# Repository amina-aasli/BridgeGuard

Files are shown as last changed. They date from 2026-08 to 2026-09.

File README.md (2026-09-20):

# BridgeGuard
**Intelligent urban flood risk prevention system using computer vision and edge computing**

BridgeGuard monitors water levels under bridges in real time, predicts flood risk using computer vision models, and automatically triggers alerts before a flood becomes critical.

---

## The problem

In Morocco, as in many other regions, flash floods regularly damage bridges and cut off vital roads often without alerts fast or localized enough. BridgeGuard addresses a simple question: **how can a bridge be monitored continuously, without human intervention, and warn people before it's too late?**

## System architecture

```mermaid
graph LR
    subgraph Field["Field Layer"]
        POWER[Power Supply]
        MODULE4G[4G Module]
        CAM[Camera 5MP]
        MPU[MPU6050]
        HCSR[HC-SR04]
        DEBIT[Flow Sensor]
        PLUIE[Rain Gauge]
    end

    subgraph Processing["Processing Layer"]
        RPI[Raspberry Pi 4]
        SUPA[(Supabase)]
        N8N[n8n]
    end

    subgraph Alert["Alert Layer"]
        APP[Web Application]
        SMS[SMS + Alerts]
        V2I[V2I Notification<br/>Automatic Rerouting]
        MAPS[Maps API]
        GEO[GPS Geofencing]
    end

    POWER --> MODULE4G
    CAM --> RPI
    MPU --> RPI
    HCSR --> RPI
    DEBIT --> RPI
    PLUIE --> RPI
    MODULE4G <--> RPI
    RPI --> SUPA
    SUPA --> N8N
    N8N --> APP
    N8N --> SMS
    N8N -.-> V2I
    GEO -.-> V2I
    MAPS --> V2I

    style RPI fill:#1a1a2e,stroke:#4a9eff,color:#fff
    style SUPA fill:#1a1a2e,stroke:#ff6b6b,color:#fff
    style V2I fill:#1a1a2e,stroke:#ffa94d,color:#fff
```

## How it works

1. **Acquisition**  a camera and 4 physical sensors (water level, vibration, flow rate, rainfall) continuously collect data on the bridge.
2. **AI analysis**  a semantic segmentation model (YOLOv8n-seg) identifies and quantifies water surfaces in the image, combined with OpenCV analysis (color-based segmentation + current speed via optical flow).
3. **Decision**  a threshold-based engine aggregates these signals into a risk score (low / moderate / critical).
4. **Active safety**  if the risk becomes critical, a second model (YOLOv8n) verifies the bridge is clear of vehicles before automatically triggering a physical barrier closure.
5. **Alert**  authorized engineers receive an SMS/email in under 4 seconds; a public dashboard informs residents of the bridge's status in real time.

## Results

| Metric | Result |
|---|---|
| Vehicle detection (YOLOv8n) | mAP50 = 0.926 |
| Water level precision (HC-SR04) | ± 0.3 cm |
| Alert response time | < 4 seconds |
| Segmentation inference speed | 12.5 ms/image |

## Tech stack

- **Edge**: Raspberry Pi 4, Python
- **Computer vision**: YOLOv8n-seg, YOLOv8n, OpenCV
- **Cloud**: Supabase (PostgreSQL + Realtime), n8n
- **Web**: React + TypeScript, Node.js + Express
- **Mechanical design**: CATIA (IP67 polycarbonate enclosure)
- **Power**: solar panel + MPPT + LiPo battery
```mermaid
graph LR
    PANEL[Solar Panel<br/>12V / 20W]
    MPPT[MPPT Controller]
    BATTERY[LiPo Battery<br/>12V / 10Ah]
    BUCK[DC-DC Buck<br/>Regulator]

    PANEL --> MPPT
    MPPT --> BATTERY
    BATTERY --> BUCK

    style PANEL fill:#1a1a2e,stroke:#ffa94d,color:#fff
    style BATTERY fill:#1a1a2e,stroke:#4a9eff,color:#fff
```

The MPPT controller optimizes solar charging efficiency (+30% vs a standard PWM controller), while the buck regulator ensures a stable 5V/3A output protecting the Raspberry Pi and sensors from battery voltage fluctuations. Total system consumption averages ~7W, giving roughly 24h of autonomy without sunlight.
## Ongoing extensions

BridgeGuard is expanding into a connected mobility ecosystem:
- **[BridgeGuard-Beacon](./beacon)** — anonymous driver notification via Wi-Fi captive portal, pre-calculated deviation routing, and an Evil Twin threat model with independent physical failsafe, validated end-to-end
- **BridgeGuard-OBU** — opt-in in-vehicle badge for connected fleets (upcoming)

## Repo structure

```
BridgeGuard/
├── hardware/       → CATIA design + electronic schematic
├── software/       → decision engine, OpenCV processing
├── ml-models/      → YOLOv8 training notebooks
├── web-app/        → frontend, backend, database
└── beacon/         → BridgeGuard-Beacon (Phase 2, see beacon/README.md)
```

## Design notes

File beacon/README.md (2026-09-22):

# BridgeGuard-Beacon

**Anonymous flood-alert notification via Wi-Fi captive portal, with an independent physical failsafe**

Second phase of BridgeGuard, extending a bridge flood-monitoring system with a Vehicle-to-Infrastructure (V2I) notification channel that reaches any smartphone, with zero app install and zero prerequisite.

---

## The problem

BridgeGuard (Phase 1) detects flood risk and closes a physical barrier automatically, but the driver approaching the bridge has no way of knowing *why* traffic is stopped, or where to go instead. Most vehicles have no native V2X connectivity, so any notification channel has to work with a standard smartphone, out of the box, without depending on installed apps.

## Why 500 m, why 3 axes

The geofencing radius isn't arbitrary, it comes directly from the physics of the approach:

- Speed limit at the bridge: **60 km/h → 16.67 m/s**
- Required advance warning window: **30 s** (reaction + comprehension + maneuver time)
- → **d = 16.67 × 30 ≈ 500 m**

Three vehicle access axes converge on the bridge (North, South-West via Bd Oued Issil, South-East via Palmeraie — two entry roads). Each was mapped and validated in QGIS to confirm beacon placement sits within the 500 m radius while accounting for real road topology.

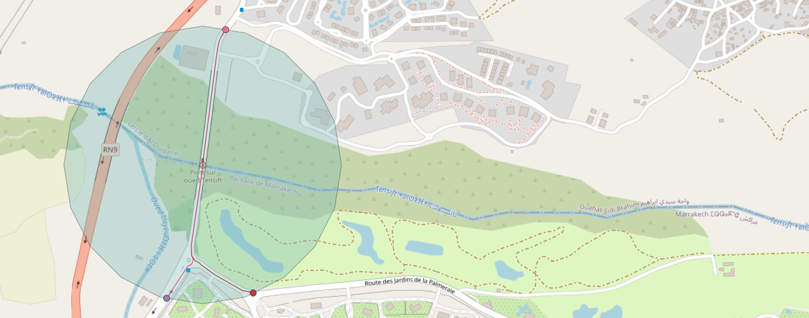
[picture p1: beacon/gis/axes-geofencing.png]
QGIS site analysis


## Architecture

```mermaid
graph TD
    subgraph Driver["Driver's smartphone"]
        PHONE[Connects to open Wi-Fi]
    end

    subgraph Beacon["ESP32 Beacon — SoftAP + STA combined"]
        AP[SoftAP<br/>open network, no password]
        DNS[DNS Server<br/>wildcard spoofing]
        HTTP[Async HTTP Server<br/>captive portal routes]
        PAGE[Alert page<br/>deviation + Maps deep link]
    end

    subgraph Cloud["Central system"]
        SUPA[(Supabase<br/>system_status)]
        DECISION[DecisionEngine<br/>Raspberry Pi — Phase 1]
    end

    PHONE -->|open network detected| AP
    AP --> DNS
    DNS -->|all queries redirected| HTTP
    HTTP --> PAGE
    PAGE -.->|deep link, driver's own data| MAPS[Google Maps]

    DECISION --> SUPA
    SUPA -->|active_alert, risk_level| HTTP

    style AP fill:#1a1a2e,stroke:#4a9eff,color:#fff
    style PAGE fill:#1a1a2e,stroke:#ff6b6b,color:#fff
    style SUPA fill:#1a1a2e,stroke:#3fb950,color:#fff
```

## How it works

1. **Detection** — the ESP32 broadcasts an open Wi-Fi network (`BridgeGuard-Alerte`) near each bridge access axis. No password, no app; the phone's own OS (iOS Captive Network Assistant, Android Connectivity Check) is the only client needed.
2. **Redirection** — a lightweight DNS server resolves every domain query to the beacon's own IP, and an async HTTP server intercepts OS-specific captive-portal probes (`/generate_204`, `/hotspot-detect.html`) to serve the alert page automatically.
3. **Guidance** — the page opens a deep link straight into the driver's own Maps app, from a hardcoded beacon-position origin to a pre-verified safe point, no live routing computed on-device, no dependency on the driver's GPS fix.
4. **Sync with the central system** — running in combined `WIFI_AP_STA` mode, the same ESP32 polls a read-only Supabase endpoint every 10 s to read the already-computed `active_alert` flag from the central DecisionEngine (Phase 1), no risk logic duplicated on the beacon.
5. **Physical failsafe** — a dedicated GPIO on the central Raspberry Pi drives an upstream warning panel, triggered in the same call as the barrier closure, independent of Wi-Fi, smartphones, or any voluntary technology adoption.

## Pre-calculated deviation routes

The beacon never computes a route on-device — it only knows two fixed points per axis: its own position, and a verified nearby point that is outside the risk zone. Guidance itself is entirely delegated to the driver's own Maps app.

| Axe | Balise (origine) | Point sûr (destination) | Distance | Itinerary |
|---|---|---|---|---|
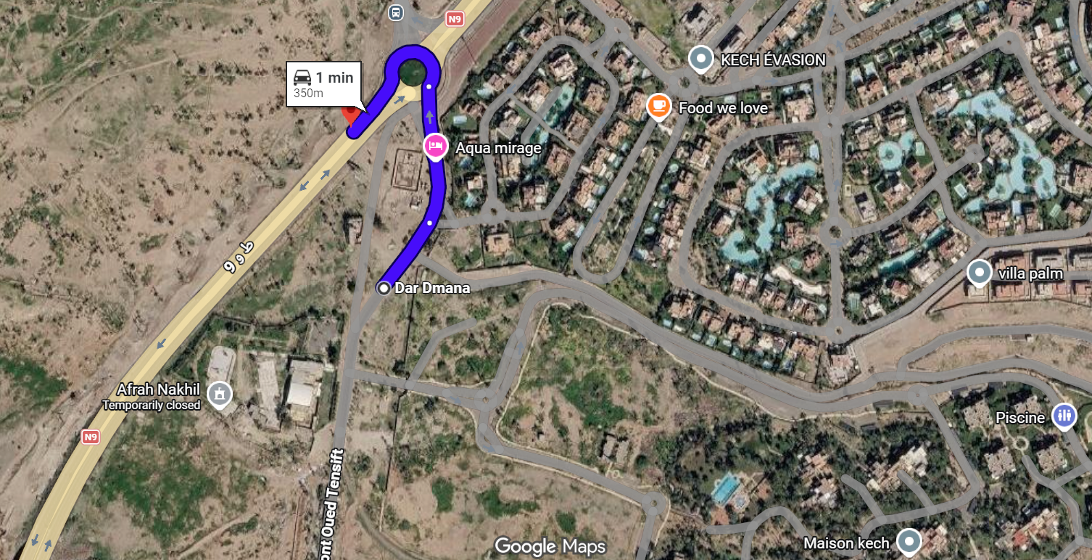
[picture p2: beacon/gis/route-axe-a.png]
| A — Nord | 31.695430, -7.987536 | 31.696762, -7.987861 | ≈ 150 m |  |
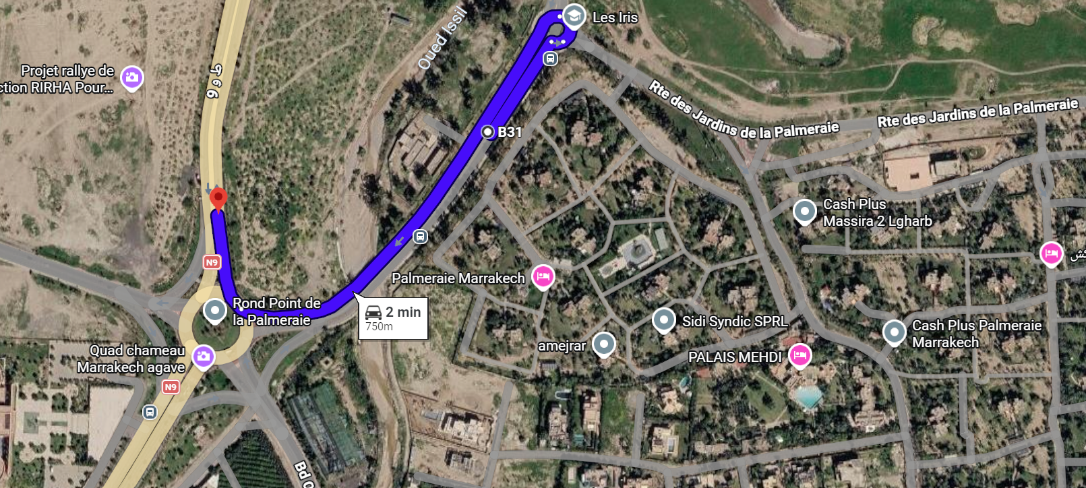
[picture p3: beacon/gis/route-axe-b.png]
| B — Sud-Ouest (Oued Issil) | 31.688102, -7.989490 | 31.687348, -7.992351 | ≈ 285 m |  |
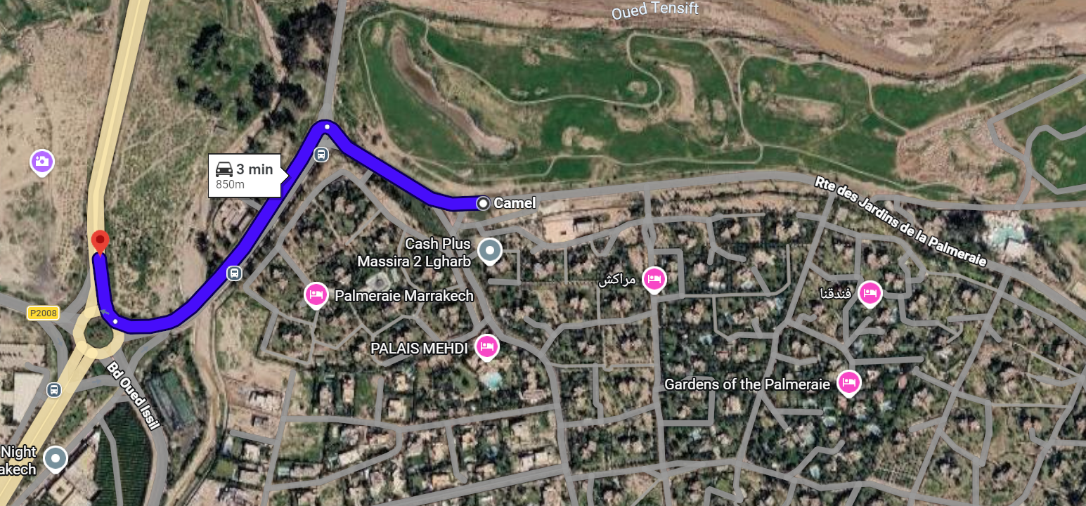
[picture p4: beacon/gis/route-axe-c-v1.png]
| C — Sud-Est (entrée 1) | 31.688106, -7.986236 | 31.687348, -7.992351 | ≈ 585 m |  |
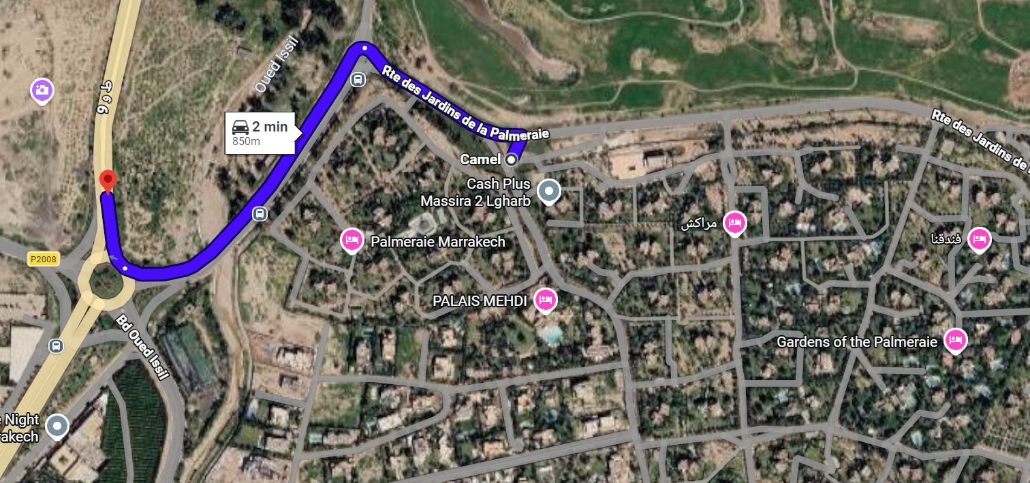
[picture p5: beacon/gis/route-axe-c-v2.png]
| C — Sud-Est (entrée 2) | 31.687806, -7.986669 | 31.687348, -7.992351 | ≈ 541 m |  |

Each destination was empirically validated against Google Maps' actual routing engine — not just estimated visually on a satellite image, since real road topology (one-way segments, roundabout connectivity) can silently reroute a seemingly short path into a much longer one.

## Multi-point deployment & corridor coverage

A single beacon covers roughly 1.8–3 s of radio exposure at 60 km/h (30–50 m theoretical Wi-Fi range). A missed contact 'locked screen, undetected notification' means the entire 30 s advance warning is lost.

Deploying **3 beacons per axis** turns this into a corridor:

- Beacon spacing: 500 m ÷ 3 ≈ **167 m**
- Latency window per missed contact: 167 m ÷ 16.67 m/s ≈ **10 s** (down from 30 s)

All beacons share the same SSID, so a phone that already joined one reconnects automatically to the next, turning Android's inconsistent auto-notification (see Results) into a non-issue on the second and third contact.

This is a probabilistic improvement, not a guarantee which is exactly why the physical failsafe (below) exists as the only non-conditional safety layer.

## Field range validation protocol

Documented (not yet executed) protocol to replace the 30–50 m theoretical Wi-Fi range with real measured coverage:

1. Move away from the beacon in 10 m increments along the road axis.
2. At each point, record: SSID visibility, RSSI (dBm), whether the alert page actually loads, and GPS coordinates.
3. Repeat in both approach directions (range isn't necessarily symmetric).
4. Map results in QGIS, overlaid on the theoretical 500 m geofencing radius.

The distinction between *SSID visible* and *page actually loads* matters because a network can stay visible past the point where throughput still allows loading the full page in time.

## The Evil Twin threat — Security posture 

An open, unauthenticated network is a deliberate trade-off: it's the only way to trigger a native captive portal without any app. But it also means the channel is structurally spoofable so anyone can broadcast the same SSID and serve a fake page.

```mermaid
graph TD
    DRIVER[Driver's smartphone]

    subgraph Legit["Legitimate network"]
        BEACON[BridgeGuard Beacon<br/>real SoftAP]
        PAGE[Real alert page<br/>verified coordinates]
    end

    subgraph Attack["Evil Twin scenario"]
        EVIL[Cloned SSID<br/>rogue access point]
        FAKE[Fake page<br/>arbitrary coordinates]
    end

    subgraph Physical["Physical safety — fully independent"]
        DECISION[Central DecisionEngine<br/>Raspberry Pi]
        GPIO[Direct GPIO]
        BARRIER[Physical barrier<br/>+ warning panel]
    end

    DRIVER -.->|identical SSID, indistinguishable| BEACON
    DRIVER -.->|identical SSID, indistinguishable| EVIL
    BEACON --> PAGE
    EVIL --> FAKE

    DECISION --> GPIO --> BARRIER
    FAKE -. can never disable .- BARRIER

    style EVIL fill:#3a0d0d,stroke:#ff4d4d,color:#fff
    style FAKE fill:#3a0d0d,stroke:#ff4d4d,color:#fff
    style BARRIER fill:#0d2818,stroke:#3fb950,color:#fff
    style DECISION fill:#0d2818,stroke:#3fb950,color:#fff
```

**This is treated as an accepted, structural limitation not a gap to patch over.** No client-side signature or watermark can protect against an attacker who simply clones the page, since the verification mechanism would be cloned along with it. Two things actually limit the real-world impact:

1. **The physical failsafe never depends on the beacon.** Barrier closure is triggered directly by the central DecisionEngine via GPIO — a compromised beacon can misinform about a detour, but can never disable the real safety mechanism.
2. **The beacon is deliberately positioned as informational, not authoritative.** Any reroute decision requiring real trust belongs to an authenticated channel — this is precisely the role of the upcoming BridgeGuard-OBU (Phase 3).

## Physical failsafe

A GPIO-driven upstream warning panel (LED array, amber/red blinking) is installed before each safe-detour divergence point, triggered in the *same* function call as the barrier closure never sequential, never software-dependent beyond a single binary GPIO state. No wireless interface, no exposed API, nothing to spoof.

This reflects the project's core safety principle: **physical safety must never depend on an action or device the user might not have.**

## Validated results

| Test | Result |
|---|---|
| Captive portal — iOS | Automatic popup, immediate |
| Captive portal — Android (Samsung One UI) | No auto-notification; page reachable via manual network access |
| Supabase read (`system_status`) | Live JSON confirmed (`risk_level`, `active_alert`, `bridge_state`) |
| Combined SoftAP + STA mode | Both interfaces stable simultaneously |
| Pre-calculated deviation routes | 4 real routes verified on Google Maps (3 axes) |

The Android limitation is a documented, known constraint of OS-level captive-portal detection not a flaw in the DNS/HTTP layer, confirmed working via manual access.

## Tech stack

- **Hardware**: ESP32 (NODE32S), PlatformIO / Arduino framework
- **Captive portal**: `WiFi.h` (SoftAP), `DNSServer`, `ESPAsyncWebServer`
- **Central sync**: `HTTPClient` → Supabase REST API (read-only, RLS-restricted key)
- **Guidance**: Google Maps universal deep link (no embedded routing engine)
- **Site analysis**: QGIS (beacon placement within the 500 m geofencing radius)

## Folder structure
```
beacon/
├── src/main.cpp          → SoftAP, DNS, HTTP server, Supabase client
├── include/
│   └── secrets.h.example → credential template
├── gis/                  → QGIS project + route/placement
├── platformio.ini
```

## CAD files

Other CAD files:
hardware/catia_files/Compartiment_secondaire.CATProduct
hardware/catia_files/Couvercle_Piece_Principale_BridgeGuard.CATProduct
hardware/catia_files/Couvercle_Second_Compartiment.CATProduct
hardware/catia_files/Porteur du GPS.CATProduct
hardware/catia_files/Porteur du camera.CATProduct
hardware/catia_files/piece principale.CATProduct

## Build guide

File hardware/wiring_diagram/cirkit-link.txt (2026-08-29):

https://app.cirkitdesigner.com/project/40ec7d5b-6bc7-4603-8445-23411d9ec829

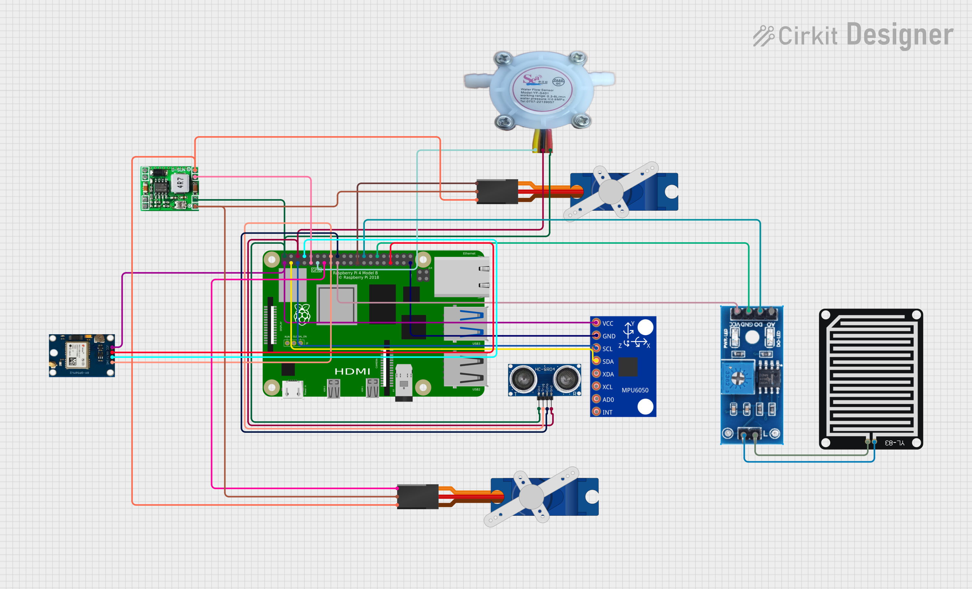
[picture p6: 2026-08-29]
hardware/wiring_diagram/bridgeguard-wiring-diagram.png

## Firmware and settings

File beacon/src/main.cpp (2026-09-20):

#include <Arduino.h>
#include <WiFi.h>
#include <HTTPClient.h>
#include <DNSServer.h>
#include <ESPAsyncWebServer.h>
#include "secrets.h"

//Configuration SoftAP
const char* AP_SSID = "BridgeGuard-Alerte";
const IPAddress AP_IP(192, 168, 4, 1);
const IPAddress AP_GATEWAY(192, 168, 4, 1);
const IPAddress AP_SUBNET(255, 255, 255, 0);

//Serveur DNS
DNSServer dnsServer;
const byte DNS_PORT = 53;

//Serveur HTTP
AsyncWebServer server(80);
unsigned long displayCount = 0; // compteur anonyme

const char alertPageHTML[] PROGMEM = R"rawliteral(
<!DOCTYPE html>
<html lang="fr">
<head>
<meta charset="UTF-8">
<meta name="viewport" content="width=device-width, initial-scale=1.0, maximum-scale=1.0, user-scalable=no">
<title>BridgeGuard — Alerte</title>
<style>
  * { margin: 0; padding: 0; box-sizing: border-box; -webkit-tap-highlight-color: transparent; }
  body {
    font-family: -apple-system, BlinkMacSystemFont, "Segoe UI", Roboto, sans-serif;
    background: #fdf1f1; color: #2b1414; min-height: 100vh;
    display: flex; flex-direction: column; align-items: center;
  }
  .page { width: 100%; max-width: 440px; min-height: 100vh; display: flex; flex-direction: column; }
  .header {
    background: linear-gradient(160deg, #ff5c5c 0%, #d92b2b 100%);
    padding: 22px 22px 26px; color: #fff; box-shadow: 0 8px 24px rgba(217, 43, 43, 0.25);
  }
  .header-top { display: flex; align-items: center; gap: 10px; margin-bottom: 14px; }
  .flood-icon { width: 38px; height: 38px; flex-shrink: 0; }
  .header-label { font-size: 11px; font-weight: 700; text-transform: uppercase; letter-spacing: 1.2px; opacity: 0.85; }
  .header-title { font-size: 20px; font-weight: 800; text-transform: uppercase; letter-spacing: 0.4px; line-height: 1.25; text-align: center; }
  .location-msg { margin-top: 12px; line-height: 1.5; background: rgba(255,255,255,0.16); border-radius: 12px; padding: 12px 14px; display: flex; flex-direction: column; align-items: center; }
  .location-row { display: flex; align-items: center; gap: 8px; }
  .location-icon { width: 18px; height: 18px; flex-shrink: 0; }
  .location-main { font-size: 14px; font-weight: 600; }
  .location-sub { font-size: 12px; opacity: 0.85; margin-top: 3px; text-align: center; }
  .cta-zone { display: flex; flex-direction: column; align-items: center; padding: 22px 20px 18px; }
  .cta-button {
    width: 156px; height: 156px; border-radius: 50%;
    background: radial-gradient(circle at 35% 30%, #3fcf6e, #1f9e4c);
    box-shadow: 0 0 0 10px rgba(31,158,76,0.12), 0 10px 30px rgba(31,158,76,0.35);
    display: flex; flex-direction: column; align-items: center; justify-content: center;
    color: #fff; text-decoration: none; border: none; cursor: pointer; transition: transform 0.12s ease;
  }
  .cta-button:active { transform: scale(0.96); }
  .cta-icon { width: 36px; height: 36px; margin-bottom: 6px; }
  .cta-label { font-size: 14px; font-weight: 800; text-transform: uppercase; letter-spacing: 0.6px; }
  .cta-caption { margin-top: 12px; font-size: 12px; color: #6b5a5a; text-align: center; line-height: 1.5; }
  .place-card { margin: 4px 20px 20px; background: #fff; border-radius: 16px; padding: 12px 14px; box-shadow: 0 2px 10px rgba(43,20,20,0.05); }
  .place-row { display: flex; align-items: center; gap: 12px; padding: 8px 4px; }
  .place-row + .place-row { border-top: 1px solid #f3e6e6; }
  .place-icon { width: 34px; height: 34px; border-radius: 10px; display: flex; align-items: center; justify-content: center; font-size: 16px; flex-shrink: 0; }
  .place-icon.dest { background: #fdecec; }
  .place-icon.origin { background: #eaf2fd; }
  .place-text-title { font-size: 13.5px; font-weight: 600; color: #2b1414; }
  .place-text-sub { font-size: 11.5px; color: #9a8a8a; margin-top: 1px; }
  .place-badge { margin-left: auto; background: #fff4d6; color: #a3760a; font-size: 11px; font-weight: 700; padding: 4px 9px; border-radius: 8px; flex-shrink: 0; }
  .footer { margin-top: auto; padding: 8px 24px 26px; text-align: center; }
  .footer-note { font-size: 11.5px; color: #9a8a8a; line-height: 1.5; }
  .anonymous-badge { display: inline-flex; align-items: center; gap: 6px; background: #fff; border-radius: 20px; padding: 6px 14px; font-size: 11.5px; color: #6b5a5a; margin-top: 12px; box-shadow: 0 2px 8px rgba(43,20,20,0.06); }
</style>
</head>
<body>
<div class="page">
  <div class="header">
    <div class="header-top">
      <svg class="flood-icon" viewBox="0 0 24 24" fill="none" xmlns="http://www.w3.org/2000/svg">
        <path d="M3 16c1.5-1.5 3-1.5 4.5 0s3 1.5 4.5 0 3-1.5 4.5 0 3 1.5 4.5 0" stroke="#fff" stroke-width="1.8" stroke-linecap="round"/>
        <path d="M3 20c1.5-1.5 3-1.5 4.5 0s3 1.5 4.5 0 3-1.5 4.5 0 3 1.5 4.5 0" stroke="#fff" stroke-width="1.8" stroke-linecap="round" opacity="0.6"/>
        <path d="M12 2v9M12 11l-3.5-3.5M12 11l3.5-3.5" stroke="#fff" stroke-width="1.8" stroke-linecap="round" stroke-linejoin="round"/>
      </svg>
      <div class="header-label">BridgeGuard · Alerte automatique</div>
    </div>
    <div class="header-title">Alerte inondation<br>danger immédiat</div>
    <div class="location-msg">
      <div class="location-row">
        <svg class="location-icon" viewBox="0 0 24 24" fill="none" xmlns="http://www.w3.org/2000/svg">
          <path d="M12 21s7-6.5 7-11.5A7 7 0 0 0 5 9.5C5 14.5 12 21 12 21Z" stroke="#fff" stroke-width="1.8" stroke-linejoin="round"/>
          <circle cx="12" cy="9.5" r="2.4" stroke="#fff" stroke-width="1.8"/>
        </svg>
        <span class="location-main">Pont de l'Oued Tensift submergé</span>
      </div>
      <span class="location-sub">Axe Nord, 300 m devant vous</span>
    </div>
  </div>
  <div class="cta-zone">
    <a class="cta-button" href="https://www.google.com/maps/dir/?api=1&origin=31.695430,-7.987536&destination=31.696762,-7.987861&travelmode=driving" target="_blank" rel="noopener">
      <svg class="cta-icon" viewBox="0 0 24 24" fill="none" xmlns="http://www.w3.org/2000/svg">
        <path d="M9 18l6-6-6-6" stroke="#fff" stroke-width="2.4" stroke-linecap="round" stroke-linejoin="round"/>
        <path d="M4 18l6-6-6-6" stroke="#fff" stroke-width="2.4" stroke-linecap="round" stroke-linejoin="round" opacity="0.5"/>
      </svg>
      <div class="cta-label">Guidage</div>
    </a>
    <div class="cta-caption">Ouvre l'itinéraire de déviation<br>directement dans votre app GPS</div>
  </div>
  <div class="place-card">
    <div class="place-row">
      <div class="place-icon dest">📍</div>
      <div>
        <div class="place-text-title">Route Nord (N9)</div>
        <div class="place-text-sub">S'éloigne de la zone inondée · point sûr le plus proche</div>
      </div>
      <div class="place-badge">+150 m</div>
    </div>
    <div class="place-row">
      <div class="place-icon origin">🧭</div>
      <div>
        <div class="place-text-title">Balise Axe Nord</div>
        <div class="place-text-sub">Point de départ du guidage — entrée du pont</div>
      </div>
    </div>
  </div>
  <div class="footer">
    <div class="footer-note">
      Cette alerte est diffusée automatiquement par BridgeGuard.<br>
      Aucune donnée personnelle n'est collectée ni requise.
    </div>
    <div class="anonymous-badge">🔒 Session anonyme</div>
  </div>
</div>
</body>
</html>
)rawliteral";

//Client Supabase embarqué
unsigned long lastPoll = 0;
const unsigned long POLL_INTERVAL_MS = 10000;

String currentRiskLevel = "low";
bool activeAlert = false;
String bridgeState = "accessible";
bool beaconActive = false;

void connectWiFiSTA() {
  Serial.print("[STA] Connexion en cours");
  WiFi.begin(WIFI_SSID, WIFI_PASSWORD);
  int attempts = 0;
  while (WiFi.status() != WL_CONNECTED && attempts < 20) {
    delay(500);
    Serial.print(".");
    attempts++;
  }
  if (WiFi.status() == WL_CONNECTED) {
    Serial.println("\n[STA] Connecté — IP : " + WiFi.localIP().toString());
  } else {
    Serial.println("\n[STA] ERREUR : échec de connexion");
  }
}

void updateActivation() {
  if (activeAlert && !beaconActive) {
    beaconActive = true;
    Serial.println("[Beacon] ACTIVÉ — risk_level = " + currentRiskLevel);
  } else if (!activeAlert && beaconActive) {
    beaconActive = false;
    Serial.println("[Beacon] DÉSACTIVÉ — retour à la normale");
  }
}

void pollSupabase() {
  if (WiFi.status() != WL_CONNECTED) {
    Serial.println("[Supabase] Pas de connexion montante — requête ignorée");
    return;
  }

  HTTPClient http;
  http.begin(SUPABASE_URL);
  http.addHeader("apikey", SUPABASE_ANON_KEY);
  http.addHeader("Authorization", String("Bearer ") + SUPABASE_ANON_KEY);

  int httpCode = http.GET();

  if (httpCode == 200) {
    String payload = http.getString();
    Serial.println("[Supabase] Réponse : " + payload);

    activeAlert = payload.indexOf("\"active_alert\":true") != -1;

    int riskIndex = payload.indexOf("\"risk_level\":\"");
    if (riskIndex != -1) {
      int start = riskIndex + 15;
      int end = payload.indexOf("\"", start);
      currentRiskLevel = payload.substring(start, end);
    }

    updateActivation();
  } else {
    Serial.printf("[Supabase] Erreur requête : code %d\n", httpCode);
  }

  http.end();
}

void handleGenerate204(AsyncWebServerRequest *request) { 
  request->redirect("http://192.168.4.1/portal"); 
} 
void handleCaptivePortal(AsyncWebServerRequest *request) {
  displayCount++;
  Serial.print("Page d'alerte affichée — compteur anonyme : ");
  Serial.println(displayCount);
  request->send_P(200, "text/html", alertPageHTML);
}

void setup() {
  Serial.begin(115200);
  delay(1000);
  Serial.println("\n[BridgeGuard-Beacon] Démarrage...");

  //Mode Access Point
  WiFi.mode(WIFI_AP_STA);
  WiFi.softAPConfig(AP_IP, AP_GATEWAY, AP_SUBNET);
  WiFi.softAP(AP_SSID, nullptr);
  Serial.print("SoftAP démarré — IP : ");
  Serial.println(WiFi.softAPIP());
  connectWiFiSTA();

  //Redirection DNS
  dnsServer.start(DNS_PORT, "*", AP_IP);
  Serial.println("Serveur DNS démarré (spoofing actif)");

  //Serveur HTTP embarqué
  server.on("/generate_204", HTTP_GET, handleGenerate204);                // Android
  server.on("/portal", HTTP_GET, handleCaptivePortal);
  server.on("/hotspot-detect.html", HTTP_GET, handleCaptivePortal);       // iOS
  server.on("/library/test/success.html", HTTP_GET, handleCaptivePortal); 
  server.on("/ncsi.txt", HTTP_GET, handleCaptivePortal);                  // Windows
  server.onNotFound(handleCaptivePortal);

  server.begin();
  Serial.println("Serveur HTTP démarré");
}

void loop() {
  dnsServer.processNextRequest();
  if (millis() - lastPoll > POLL_INTERVAL_MS) {
  lastPoll = millis();
  pollSupabase();
}
}
